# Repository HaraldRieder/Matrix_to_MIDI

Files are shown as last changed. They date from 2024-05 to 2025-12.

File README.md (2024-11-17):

## MIDI Controller mit Keyboard Diodenmatrix

Dieses Archiv enthält Dokumentation und Arduino-Quellcode zum Bau eines MIDI Instruments mit 6+6 Tastatur, die über eine Diodenmatrix abgefagt wird.
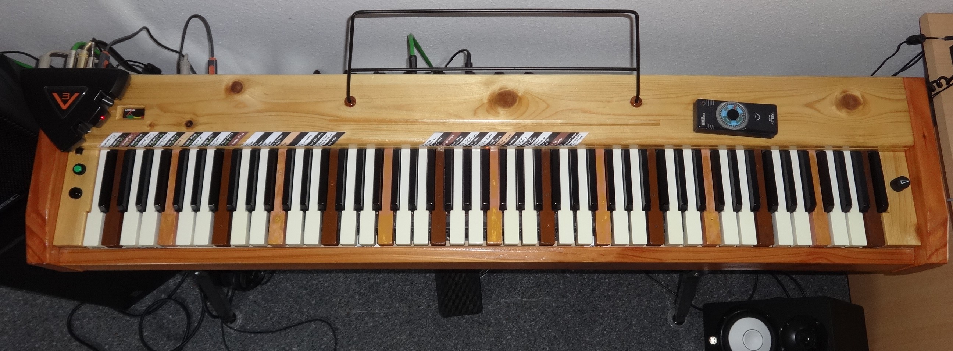
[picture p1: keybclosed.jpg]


Die Diodenmatrix basiert auf 8 Sammelleitungen und jeweils 11 Leitungen für Arbeits- und Ruhekontakte. Damit kann die Tastatur maximal 8x11=88 Tasten besitzen. Solche Matrizen wurden zum Beispiel in FATAR Tastaturen, die in Doepfer Masterkeyboards integriert wurden, eingesetzt.
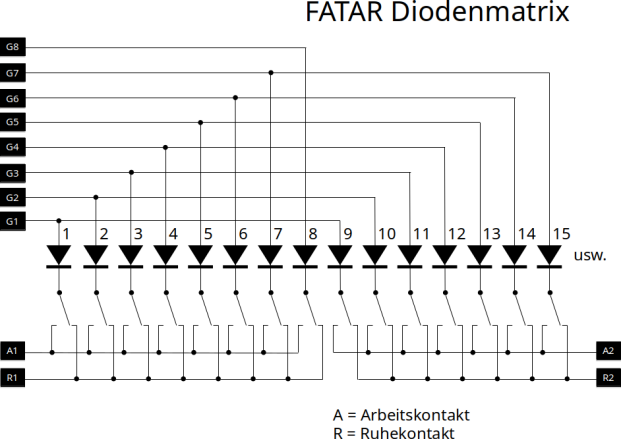
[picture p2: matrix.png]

Die Unterstützung anderer Tastaturen ist möglich, erfordert aber eine Code-Anpassung.

Ursprünglich als reines MIDI Keyboard mit hochwertiger Tastatur geplant hat sich das Projekt weiter entwickelt. Ein MIDI Modul, hier ein V3 Sound Grand Piano XXL, kann spezifisch angesteuert werden. Ein Keyboard-Splitpunkt wird unterstützt. Gesendet wird auf bis zu 3 MIDI Kanälen. Unterstützung anderer MIDI Module ist möglich, erfordert aber eine Code-Anpassung.

## Blockschaltbild und Anschlüsse
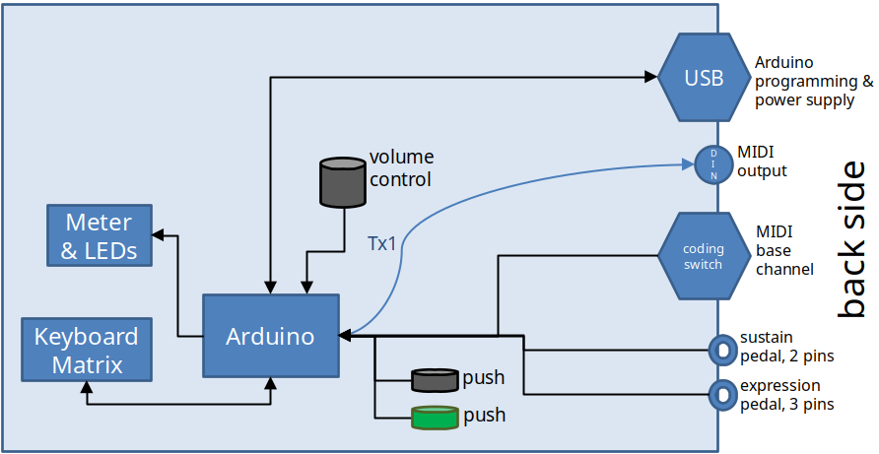
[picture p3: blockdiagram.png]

### Ein- und Ausgänge

- 5-pol. DIN Buchse MIDI Ausgang
- 6,3 mm Mono-Klinkenbuchse für Haltepedal
- 6,3 mm Stereo-Klinkenbuchse für Schwellerpedal
- USB Typ B Buchse für Arduino-Programmierung oder Stromversorgung. Praktisch: wird tatsächlich ein V3 Sound Modul verwendet, dann kann dessen USB Anschluss, der vom Herstellen eigentlich für einen Bluethooth-Stick vorgesehen ist, das MIDI Keyboard mit Strom mitversorgen.

### Bedienelemente

- Stufenschalter zur Festlegung der MIDI-Kanäle
- Drehregler rechts für Gesamtlautstärke
- Ein schwarzer und ein grüner Taster links
- Ein Zeigerinstrument mit schaltbarer Hintergrundbeleuchtung (weiße LED)
- Eine orange LED über der Tastaturmitte
- Die Tastatur selbst

## Schaltpläne

Zentraler Bestandteil der Elektronik ist ein Arduino Mega 2560 Board. Nur wenige Bauteile sind notwendig zur Anpassung an die Peripherie. Je Arbeits- und Ruhekontaktleitung der Tastaturmatrix wird ein 1 kOhm Widerstand benötigt.

Der Maximalausschlag des Zeigerinstruments kann mit Hilfe eines Trimmers justiert werden.

Die Pegel der externen Pedale werden über Kondensatoren leicht geglättet. Der 1,2 kOhm Widerstand schützt vor Kurzschlüssen, denn an der Buchse für das Schwellerpedal finden sich sowohl +5V als auch Masse. Das Schwellerpedal muss hochohmig sein, damit der 1,2 kOhm Widerstand nicht die Vollaussteuerung verhindert.
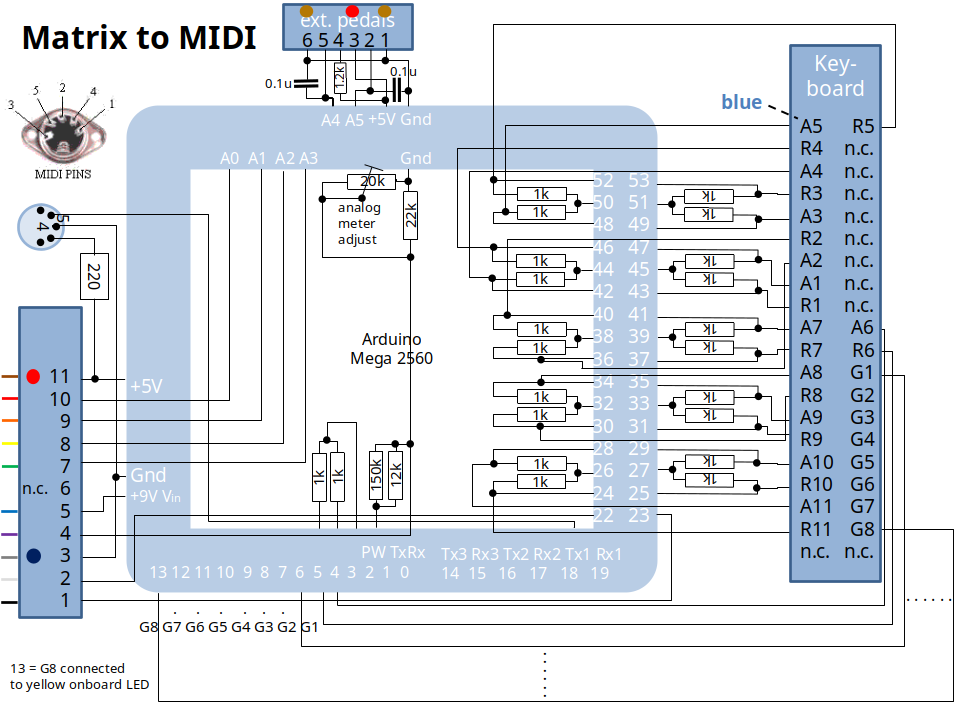
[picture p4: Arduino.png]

Besonderheit: Zur Einsparung von Arduino-Eingängen wird die Stellung des Codierschalters mittels 5 Widerständen D/A-gewandelt. Die Software reduziert den am Analogeingang gemessenen, 1024 Werte feinen digitalen Wert wieder in eine Schalterstellung von 0 bis 9.
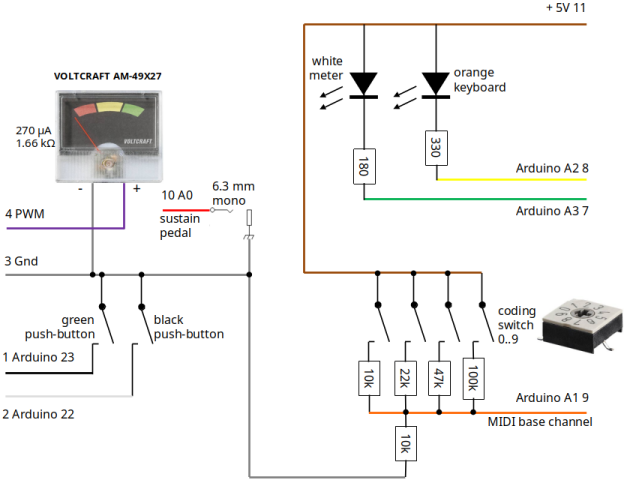
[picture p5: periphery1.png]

Die weiße LED ist die Hintergrundbeleuchtung des Zeigerinstruments, die orangene die über der Tastatur.
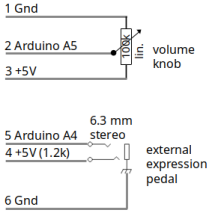
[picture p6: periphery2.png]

Das von mir verwendete Schwellerpedal von Dr. Böhm enthält ein logarithmisches 180° Potentiometer mit 470 kOhm. Die Software muss zurückrechnen. Im [Code](Matrix_to_MIDI.ino) vorgesehen ist aber auch der Anschluss linearer Potentiometer (siehe die Bedingung um den Aufruf von `delog()`).

## Hardware

Alles zusammen ist in einem selbstgebauten Holzgehäuse untergebracht. Die Tastatur kann zu Wartungszwecken ohne Werkzeug ausgebaut werden. Die obere Klappe wird lediglich durch 2 quadratische Permanentmagnete links und rechts geschlossen gehalten. Sie kann von Hand durch einen gewissen Krafteinsatz geöffnet werden.
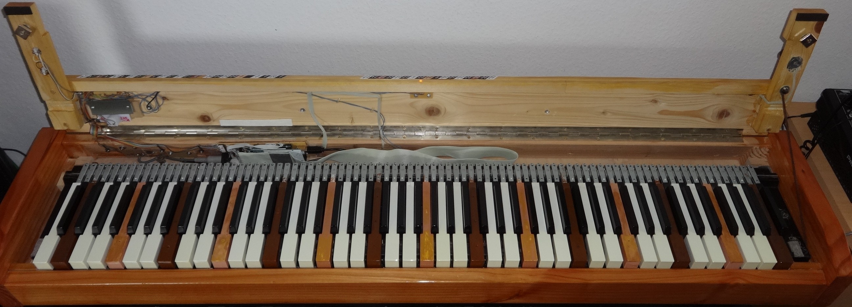
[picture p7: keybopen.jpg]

Die Tastatur wird durch 2 Klemmblöcke links und rechts fixiert. Bei geöffneter Klappe lassen sich diese Holzblöcke nach oben entnehmen. Danach kann die Tastatur nach hinten bis zum Anschlag geschoben und nach oben herausgenommen werden.

Arduino- mit Mother-Board (Lochrasterplatine) befinden sich stehend in der linken Hälfte. Um die zusammengesteckten Boards zu entnehmen müssen alle Steckverbinder zum Mother-Board gelöst werden. Die Boards werden nur durch die geschlossene Klappe fixiert und können bei geöffneter Klappe vorsichtig nach oben entnommen werden. Ein Ausbau der Tastatur ist nicht notwendig.

Dies ist das mit Abstand wartungsfreundlichste Keyboard, das ich in meinem Musikerleben hatte, und es gab derer nicht wenige.

## Bedienung

### MIDI-Kanäle einstellen

Das Instrument sendet auf bis zu 3 aufeinanderfolgenden MIDI Kanälen, die über den Codierschalter einzustellen sind. Der Codierschalter wird nur beim Hochfahren ausgelesen
in der Zeit, in der die Hintergrundbeleuchtung des Zeigerinstruments an ist. Für den Wechsel der MIDI Kanäle muss das Instrument also aus- und wieder eingeschaltet werden.

Circa 5 Sekunden nach dem Einschalten werden außerdem

* ein General MIDI Reset gesendet (SYSEX)
* V3 Reverb Type auf Room 2 und Effect Type auf Chorus 1 gestellt (SYSEX)
* V3 Main und AUX Equalizer flach[^1] gestellt (MIDI NRPNs)

[^1]: Nach dem Einschalten sind die XXL EQs *nicht* flach eingestellt!

#### Ohne Split

Nach dem Einschalten ist die Tastatur nicht geteilt. Das Instrument sendet auf dem Kanal, der am Codierschalter eingestellt wurde. Dabei fängt MIDI bei 1 an zu zählen und der Codierschalter bei 0. Das Haltepedal bestimmt den _Sustain_ Wert, der Schweller den _Expression_ Wert. Oft bestimmt der _Expression_ Controller die Lautstärke, das hängt vom MIDI Modul und dessen Einstellungen ab.

*Beispiel: Der Codierschalter steht auf 4, dann wird auf MIDI-Kanal 5 gesendet.*

#### Mit Split

Das Instrument sendet auf 3 aufeinanderfolgenden Kanälen. Der linke Tastaturbereich sendet auf dem 1. der Kanäle, der rechte Tastaturbereich sendet auf dem 2. und 3. der Kanäle. Der Schweller regelt den _Expression_ Wert auf dem 2. der Kanäle.

*Beispiel: Der Codierschalter steht auf 2, dann sendet der linke Tastaturbereich auf MIDI-Kanal 3, der rechte Tastaturbereich sendet parallel auf den Kanälen 4 und 5. Der Schweller regelt nur Kanal 4.*

Im Splitmodus hat man normalerweise links und rechts verschiedene Sounds. Mit dem Schweller lässt sich auf der rechten Seite ein weiterer, dritter Sound als _Layer_ hinzuregeln. Natürlich kann man auf dem 3. der Kanäle auch einen stummen Sound einstellen und trotzdem mit dem Schweller den 2. der Kanäle regeln.

##### Transponierung

Der rechte Tastaturbereich transponiert fest um -12.

Der linke Tastaturbereich transponiert zunächst nicht. Diese Einstellung eignet sich dazu, mit der linken Hand Bass zu spielen. Da beim monophonen Bassspiel _Sustain_ so gut wie nie benötigt wird, sendet das Haltepedal auf dem 2. und den 3. der Kanäle, also für den rechten Bereich.

Der linke Bereich kann auf eine Transponierung +12 umgeschaltet werden. Diese Einstellung eignet sich dazu, mit der linken Hand Akkorde zu spielen. Das Haltepedal sendet dann auf dem 1. der Kanäle, also für den linken Bereich.

### Globale Anschlagsdynamik einstellen

Durch langes Drücken (> 2,5 Sekunden) des schwarzen Tasters gelangt man in den Justiermodus für die globale Anschlagsempfindlichkeit. Das Zeigerinstrument wird beleuchtet und zeigt den eingestellten Wert an. Drückt man eine Taste, wird die MIDI _Velocity_ angezeigt, wie sie über MIDI gesendet wird. Dem Vollausschlag des Zeigers entspricht ein Wert von 127. Nach Loslassen der Taste wird wieder die eingestellte globale Empfindlichkeit angezeigt. Der Empfindlichkeitswert kann mit dem grünen Taster schrittweise vermindert und mit dem schwarzen Taster erhöht werden.

Diese Funktion ist zur Anpassung an das verwendete MIDI Modul gedacht.

Um den Justiermodus zu verlassen muss der schwarze Taster nochmals lange gedrückt werden.

### Anschlagsdynamik je Taste justieren

Durch langes Drücken (> 2,5 Sekunden) des grünen Tasters gelangt man in den Feinjustiermodus. Die Empfindlichkeit lässt sich je Taste nachjustieren. Oft sind Ober- und Untertasten aufgrund der Bauweise der jeweiligen Tastatur verschieden zu justieren. Drückt man eine Taste, wird die MIDI _Velocity_ angezeigt, wie sie über MIDI gesendet wird. Dem Vollausschlag des Zeigers entspricht ein Wert von 127. Nach Loslassen der Taste wird die eingestellte Empfindlichkeit der Taste angezeigt. Der Empfindlichkeitswert kann mit dem grünen Taster schrittweise vermindert und mit dem schwarzen Taster erhöht werden.

Diese Funktion ist zur Anpassung an die verwendete Tastatur gedacht.

Um den Feinjustiermodus zu verlassen muss der grüne Taster nochmals lange gedrückt werden.

### Keyboard Split

Durch gleichzeitiges (kurzes) Drücken beider Taster lässt sich ein Splitpunkt festlegen. Die orangene LED blinkt, bis eine Taste gedrückt wird. Die gedrückte Taste legt den Splitpunkt fest. Im Splitmodus leuchtet die orangene LED heller.

Um den Splitmodus zu verlassen müssen wieder beide Taster gleichzeitig gedrückt werden. Die orangene LED leuchtet nun dunkler, so wie nach dem Einschalten.

#### Transponierung linker Bereich

Im Splitmodus lässt sich die Transponierung des linken Bereichs zwischen 0 und +12 umschalten. Dazu ist der schwarze Taster kurz zu drücken. Das Zeigerinstrument wird für 1,5 Sekunden beleuchtet und meldet die eingestellte Transponieren zurück, das heißt der Zeiger befindet sich entsprechend am linken oder am rechten Anschlag.

### V3 Grand Piano Ansteuerung
Unterstützt wird das Einstellen von

- Sounds mittels Bank Select und Program Change Nachrichten.
- Registrierungen im Sinne von V3 Sound Registrierungen für die bis zu 3 Kanäle im Splitmodus.

#### Sounds

Ohne Splitpunkt kann keine Registrierung eingestellt werden. Es können auch keine Sounds aus der Bass-Gruppe (grün) eingestellt werden.

Nach kurzem Drücken des grünen Tasters lässt sich ein Sound auswählen. Die orangene LED blinkt, bis eine Taste aus dem linken Bereich gedrückt wird. Die gedrückte Taste wählt den Sound aus. Die Sounds sind im [Quellcode](V3GrandPianoXXL.h) festzulegen. Aufkleber helfen beim Finden der zu drückenden Taste.

Die Namen der Sounds wurden denen aus dem V3 Handbuch entlehnt, z.B. _GP Hamburg_ für _Grand Piano Hamburg_ oder _Upright Bs_ für _Upright Jazz Bass_.

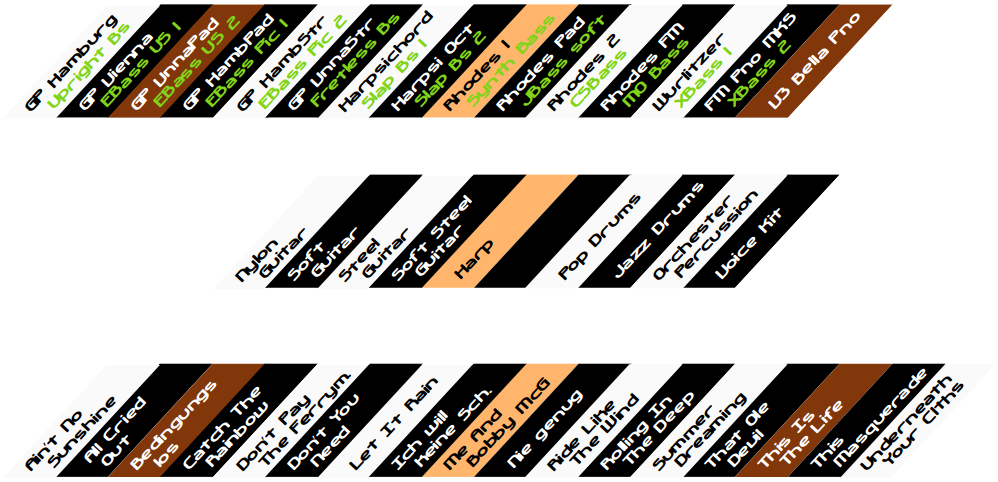
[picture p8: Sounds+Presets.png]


#### Registrierungen

Eine Registrierung besteht aus globalen Einstellungen und 3 Presets.

Als globale Einstellungen werden unterstützt

- Reverb Type
- Effect Type

Ein Preset besteht derzeit aus den kanalspezifischen Einstellungen

- Bank Select + Program Change
- Channel Volume
- Coarse Tuning
- Reverb Level
- Choruse Level
- Attack
- Decay
- Release
- Cutoff Frequency

Nach kurzem Drücken des grünen Tasters lässt sich eine Registrierung auswählen. Die orangene LED blinkt, bis eine Taste gedrückt wird. Eine gedrückte Taste ab der Tastaturmitte wählt die Registrierung aus. Die Registrierungen sind im [Quellcode](V3GrandPianoXXL.h) festzulegen. Aufkleber helfen beim Finden der zu drückenden Taste. Die Registrierungen wurden nach den Musiktiteln benannt, wo sie erstmalig zum Einsatz kamen, z.B. _Ain't No Sunshine_.

Wird bei blinkender LED eine Taste gewählt, die einen Sound auswählt (linke Tasten) und nicht eine Registrierung, dann betrifft dies den 1. der Kanäle, also den linken Bereich. So lässt sich zum Beispiel im Splitmodus nach Auswahl der Registrierung nachträglich der Bass- (kein Transpose) oder Begleit-Sound (bei Transpose +12) ändern.

### Zustandsdiagramme
#### Einschalten, Justieren, Split festlegen
Nach dem Einschalten wird nach einigen Sekunden der _Normalzustand_ `playing` erreicht. Alle anderen Zustände wird man nur von Zeit zu Zeit besuchen.
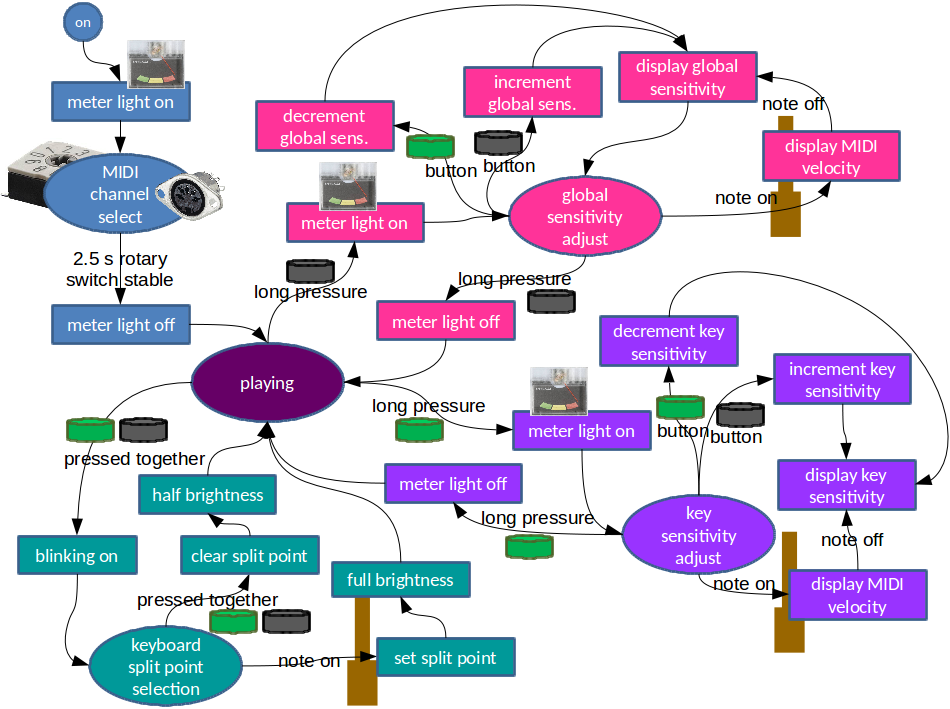
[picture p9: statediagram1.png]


#### Transponieren und Sound/Preset auswählen
`playing` ist identisch mit dem bereits erwähnten Normalzustand. Um das obige Diagramm nicht zu überfrachten, wurde dieses weitere Diagramm erstellt.
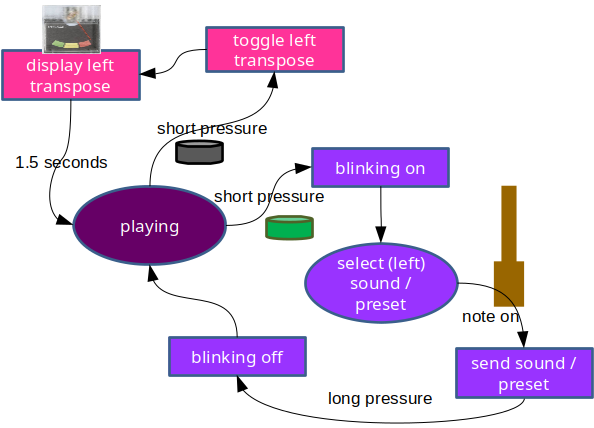
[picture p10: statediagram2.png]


## FATAR Tastatur, sehr hochwertig aber inklusive Zeitbombe

Meine LMK3 Tastatur wurde wahrscheinlich im Jahr 1991 hergestellt und dank leicht zu reinigender, versilberter Spiralschalter funktioniert sie 2024 noch tadellos.
Allerdings hat die Tastatur einen Design-Fehler, der mit ziemlichem Aufwand behoben werden muss.
Für Dämpfung sorgen Filze und Gummis. Die Gummis haben eine zusätzliche Funktion: sie führen die Tasten seitlich. Und das ist ein Problem.
Gummiabrieb sammelt sich schon nach Monaten auf den metallenen Innenseiten der Tasten, und danach reibt Gummi auf Gummi.
Wird die Taste genau senkrecht nach unten gedrückt, stört es nicht. Mit seitlicher Kraft nach rechts oder links widerborstet sie aber erheblich.
So kann nicht ernsthaft Klavier gespielt werden!

Dagegen habe ich jahrelang mit nähgarnumwickelten Gummis gearbeitet. Bei 88 Gummis ist das ein Riesenaufwand.
Und nach Jahren sind manche Garne abgerieben und es bremst wieder bei seitlichem Niederdrücken.

Bei neu aufgetauchten Widerborsten mussten nun die seitlichen Gummiführungen ganz weichen. Ich habe sie weggeschnitten, wodurch von jedem Gummi nur noch Ober- und Unterteil übrig bleiben.
Diese werden nicht mehr von vorne auf die vorgesehenen Stahlhalterungen geschoben, was mangels Loch nicht mehr geht, sondern aufgeklebt.
Die seitliche Führungsarbeit wird von 0,9 mm Garnierungsfilzen (von Meyne) übernommen. Bisher funktioniert das einwandfrei.
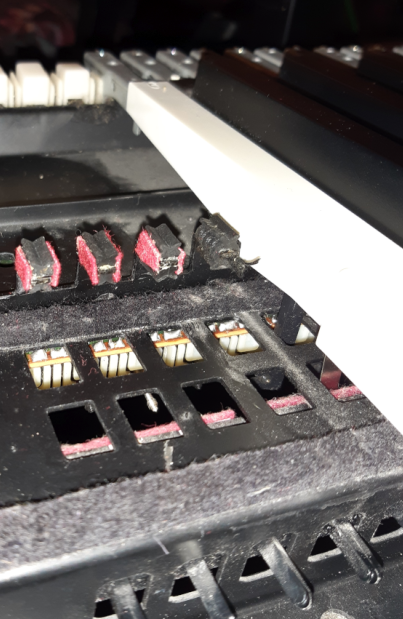
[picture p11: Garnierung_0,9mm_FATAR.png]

Auf dem Bild sieht man links 3 zerschnittene Gummis mit seitlichen, roten Filzführungen, daneben noch ein garnumwickelter Gummi.

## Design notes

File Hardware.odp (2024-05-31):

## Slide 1

push

push

back side

volume
control

USB

Arduino

programming &
power supply

DIN

MIDI

output

MIDI

base

channel

Meter

& LEDs

Tx1

coding switch

Arduino

Keyboard
Matrix

sustain

pedal, 2 pins

expression

pedal, 3 pins

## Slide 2

Arduino

Mega 2560

52 53

50 51

48 49

46 47

44 45

42 43

40 41

38 39

36 37

34 35

32 33

30 31

28 29

26 27

24 25

22 23

Tx3 Rx3 Tx2 Rx2 Tx1 Rx1
14 15 16 17 18 19

+5V

Gnd +9V Vin

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
Matrix to MIDI

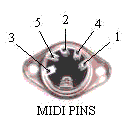
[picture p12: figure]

12k

150k

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
Key-

board

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
n.c.

ext. pedals

6 5 4 3 2 1

1.2k

A4 A5

A0 A1 A2 A3

0.1u

0.1u

+5V Gnd

Gnd

blue

R5

n.c.

n.c.

n.c.

n.c.

n.c.

n.c.

n.c.

n.c.

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
n.c.

PW TxRx

13 12 11 10 9 8 7 6 5 4 3 2 1 0

analog
meter

adjust

n.c.

G8 G7 G6 G5 G4 G3 G2 G1

13 = G8 connected

to yellow onboard LED

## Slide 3

330

180

10k

22k

47k

100k

10k

+ 5V 11

VOLTCRAFT AM-49X27

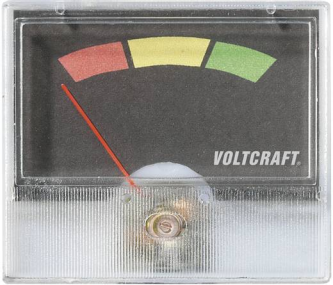
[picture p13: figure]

- +

white

meter

orange

keyboard

270 μA

1.66 kΩ

Arduino A2 8

Arduino A3 7

4 PWM

10 A0

sustain
pedal

6.3 mm
mono

n.c.

3 Gnd

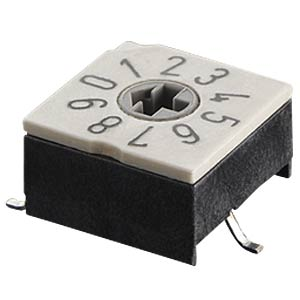
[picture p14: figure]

Arduino A1 9

green

push-button

1 Arduino 23

2 Arduino 22

black

push-button

coding

switch

0..9

MIDI base channel

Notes: 7

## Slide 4

100k
lin.

1 Gnd

2 Arduino A5

3 +5V

volume
knob

5 Arduino A4

4 +5V (1.2k)

6.3 mm
stereo

external
expression
pedal

6 Gnd

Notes: 7

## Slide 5

2.5 s rotary

switch stable

long pressure

button

button

note on

note off

long pressure

long pressure

long pressure

button

button

note on

note off

pressed together

note on

pressed together

on

meter light on

MIDI channel select

decrement global sens.

increment global sens.

display global sensitivity

display MIDI velocity

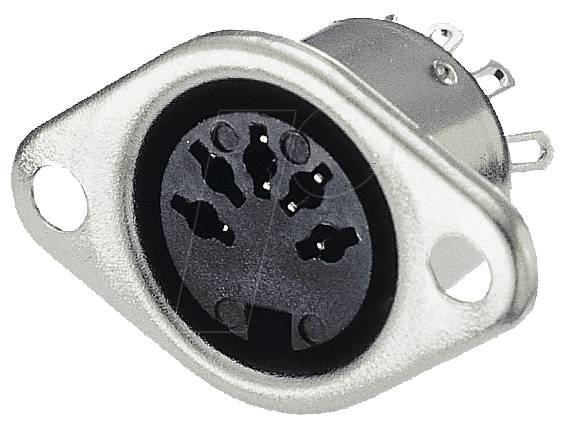
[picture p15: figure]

meter light on

global sensitivity

adjust

meter light off

meter light off

playing

decrement key sensitivity

increment key sensitivity

meter light on

half brightness

meter light off

display key sensitivity

key sensitivity

adjust

blinking on

clear split point

full brightness

display MIDI velocity

keyboard split point selection

set split point

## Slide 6

short pressure

1.5 seconds

short pressure

long pressure

note on

display left
transpose

toggle left transpose

blinking on

playing

select (left) sound / preset

blinking off

send sound / preset

## FATAR Diodenmatrix

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
usw.

A1

A2

R1

A = Arbeitskontakt

R = Ruhekontakt

R2

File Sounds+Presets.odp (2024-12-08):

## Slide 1

GP Vienna
EBass US 1

GP Hamburg
Upright Bs

GP VnnaPad
EBass US 2

Rhodes 1
Synth Bass

GP HambPad
EBass Pic 1

GP HambStr
EBass Pic 2

Harpsichord
Slap Bs 1

GP VnnaStr
Fretless Bs

Harpsi Oct
Slap Bs 2

Rhodes Pad
JBass soft

Rhodes FM
MO Bass

FM Pno MKS
XBass 2

Rhodes 2
CSBass

Wurlitzer
XBass 1

V3 Bella Pno

Harp

Nylon

Guitar

Steel

Guitar

Soft

Guitar

Soft Steel
Guitar

Jazz Drums

Voice Kit

Pop Drums

Orchester

Percussion

All Cried

Out

Ain’t No

Sunshine

Bedingungs

los

Me And

Bobby McG

Catch The

Rainbow

Don’t Pay

The Ferrym.

Let It Rain

Don’t You

Need

Ich will

keine Sch.

Nie genug

Rolling In

The Deep

That Ole

Devil

Ride Like

The Wind

Summer

Dreaming

This Is

The Life

Underneath

Your Clths

This

Masquerade

Ain’t Nobody

Streifenhöhe 3 cm, Streifenbreite/Tastenabstand 1,375 cm, Impress Grid dx = 1,38 cm dy = 1 cm, Schriftwinkel atan(3/2/1,38) = 47,39°

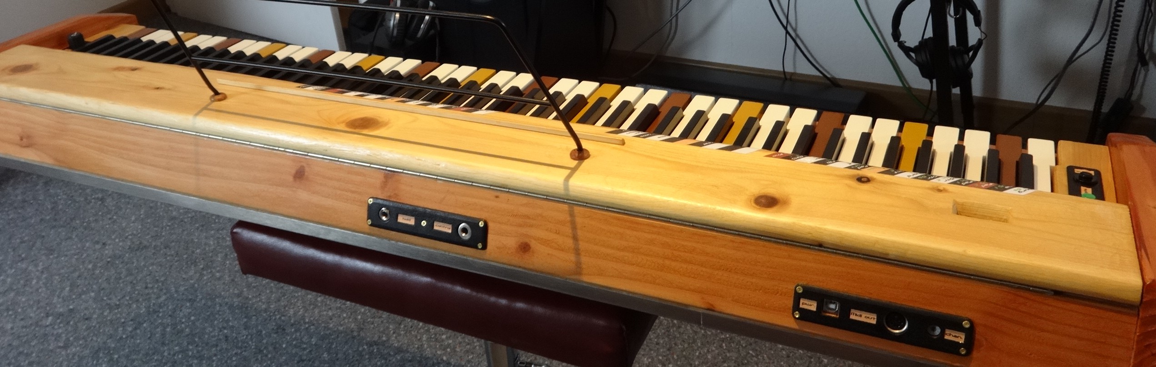
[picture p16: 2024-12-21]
refurbished_back.JPG

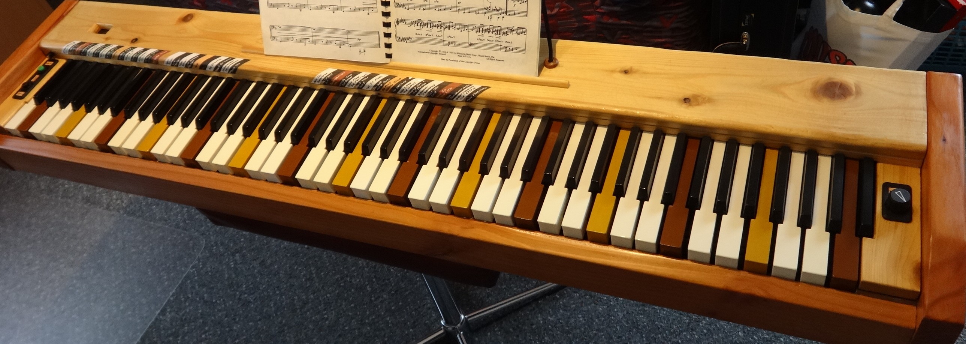
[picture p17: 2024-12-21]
refurbished_front.JPG

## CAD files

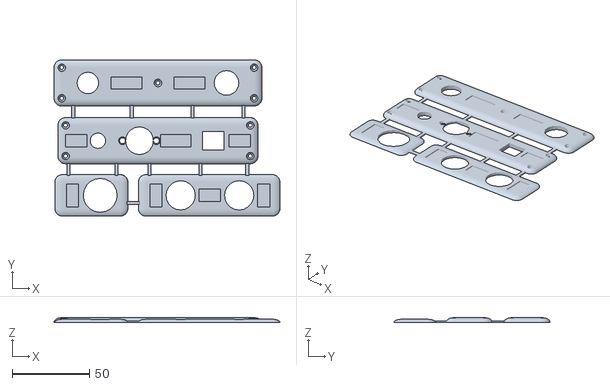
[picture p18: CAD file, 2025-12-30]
Matrix to MIDI Plates.stl
146.8 x 101.5 x 3.00

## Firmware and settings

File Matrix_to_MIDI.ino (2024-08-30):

/**************** WARNING ****************

This project runs successfully on Arduino Mega 2560 when built with Arduino 2: 1.0.5+dfsg2-4 IDE.
Chosen board: Arduino Mega 2560 or Mega ADK

This project did out-of-the-box *NOT* run on Arduino Mega 2560 when built with Arduino 1.8.10!
The software crashed and the board booted cyclically.

I found out that the direct port I/O in Matrix.h was responsible. For other reasons
I changed the compiler option to -O3 and this seems to have repaired the 
direct port I/O code, too. See platform.txt.

***************** WARNING *****************/

#include <midi_Message.h>
#include <midi_Namespace.h>
#include <MIDI.h>
#include <midi_Defs.h>
#include <midi_Settings.h>

#include <EEPROM.h>
#include "Matrix.h"
#include "Dynamic.h"
#include "Matrix_to_MIDI.h"
#include "ScaleTune.h"
#include "CodingSwitch.h"
#include "V3GrandPianoXXL.h"

MIDI_CREATE_INSTANCE(HardwareSerial, Serial1, midi1);

midi::Channel channel = 1;

/*--------------------------------- setup and main loop ---------------------------------*/

int slice_counter = 0;
const int n_slices = 6;

const int keyboard_led_pin = A2; // = F2 ATMega port+bit

const int no_key = -1;
int last_key = no_key;
int split_position = no_key;
int left_transpose = 0;

const int black_button_pin = 22;
const int green_button_pin = 23;
const int external_switch_pin = A0; // = F0 ATMega port+bit
const int external_control_pin = A4; 
int external_control_val = 1023; // 0..1023 analog value
int external_val = MIDI_CONTROLLER_MAX; // 0..127 MIDI value
const int volume_control_pin = A5;
int volume_control_val = 1023; // 0..1023 analog value
int volume_val = MIDI_CONTROLLER_MAX; // 0..127 MIDI value
boolean black_button = false; // "up"
boolean green_button = false; // "down"
int external_switch = LOW;

void setup() {
  Serial.begin(9600); // debugging
  pinMode(black_button_pin, INPUT_PULLUP);
  pinMode(green_button_pin, INPUT_PULLUP);
  pinMode(external_switch_pin, INPUT_PULLUP);
  pinMode(meter_pin, OUTPUT);
  pinMode(meter_led_pin, OUTPUT);
  pinMode(keyboard_led_pin, OUTPUT);
  digitalWrite(keyboard_led_pin, HIGH);
  
  // user has 5 seconds (re-triggerable timer) to adjust MIDI channel
  digitalWrite(meter_led_pin, LOW);
  channel = readCodingSwitchValue(A1) + 1; // 0=omni, 1..16 are individual channels, 17=off
  displayChannel(channel);
  for (int i = 1; i <= 20; i++) {
    delay(250);
    byte newChannel = readCodingSwitchValue(A1) + 1;
    displayChannel(newChannel);
    if (newChannel != channel) {
      channel = newChannel;
      i = 0;
    }
  } 
  digitalWrite(meter_led_pin, HIGH);
  display(0);
  // V3 XXL needs these 5 seconds to get ready!
  
  setupMatrixPins();

  readSettings();
  initVelocities(global_sens_to_exponent(settings.sensitivity));

  midi1.begin(1/*dummy input channel*/);
  sendGMReset(midi1);
  sendReverbType(1, midi1); // Room 2
  for (int i = 0; i < 3; i++) {
    midi1.sendControlChange(midi::Effects1, 15, channel+i); // Room 2 -> lower reverb send level

  }
  sendEffectType(0, midi1); // Chorus 1
  flattenEQs(midi1);

  // disable timers / avoid jitter
  //TIMSK0 = 0; leave timer 0 enabled so that we still have delay() and millis() but not tone()
  TIMSK1 = 0;
  TIMSK2 = 0;
  //TIMSK3 = 0; we need timer 3 for PWM at pin 2
  TIMSK4 = 0;
  TIMSK5 = 0;

  Serial.println("ready");
}

// max. time Arduino consumes between 2 calls of loop()
int max_ex_scan_time_us = 0;
int t_start = -1;

// blinking LEDs
const int period = 400/*ms*/;
unsigned long last_blink = 0/*ms*/;
boolean keyboard_led_on = false;

/* 3 dodecimes to select left sounds */
const midi::DataByte right_sounds_start = 12*3;

// report the max. time between calls of scanMatrix, highest observed value: 24 us
//#define DEBUG_EX_SCAN_TIME

State state = idle;

void loop() {
  static int i_led;

  unsigned long t = millis();
  int inval;
  switch (slice_counter) {
    case 0:
      buttons(t);
      break;
    case 2:
      inval = analogRead(volume_control_pin);
      // if changed, with +-2 jitter suppression
      if (inval > volume_control_val + 2 || inval < volume_control_val - 2) {
        volume_control_val = inval;
        inval /= 8;
        if (inval != volume_val) {
          sendMasterVolume(volume_val = inval, midi1);
          //Serial.print("volume val "); Serial.println(volume_val);
        }
      }
      break;
    case 4:
      inval = analogRead(external_control_pin);
      // if changed, with +-2 jitter suppression
      if (inval > external_control_val + 2 || inval < external_control_val - 2) {
        external_control_val = inval;
        if (true) inval = delog(inval)/8; // for logarithmic/audio pedals
        else inval /= 8; // for linear pedals
        if (inval != external_val) {
          externalControl(external_val = inval);
          //Serial.print("external val "); Serial.println(external_val);
        }
      }
      break;
    default:       
      externalSwitch();
  }
  
  switch (state) {
    case idle: case global_sensitivity:
      switch (++i_led) {
        case 10:
          //digitalWrite(keyboard_led_pin, LOW);
          PORTF &= 0xfb;
          keyboard_led_on = true;
          break;
        case 11:
          if (split_position == no_key) {
            //digitalWrite(keyboard_led_pin, HIGH);
            PORTF |= 0x04;
            keyboard_led_on = false;
          }
          i_led = 0;
          break;
      }
      break;
    default:
      if (t >= last_blink + period) {
        last_blink = t;
        process(toggle_led, -1, -1);
      }
  }
  
  #ifdef DEBUG_EX_SCAN_TIME
  if (t_start > 0) {
    int ex_scan_time_us = micros() - t_start;
    if (ex_scan_time_us > max_ex_scan_time_us) {
      max_ex_scan_time_us = ex_scan_time_us;
      Serial.print(max_ex_scan_time_us); Serial.println(" microseconds max. ex. scan");
    }
  }
  // typical max. value: 20 microseconds
  #endif
  
  scanMatrix();

  #ifdef DEBUG_EX_SCAN_TIME
  t_start = micros();
  #endif
  
  slice_counter++;
  if (slice_counter >= n_slices) {
    slice_counter = 0;
  }
}

int delog(int value) {
  static int half = 120;
  if (value <= half) {
    //Serial.print("delog - ");Serial.print(value);Serial.print("->");Serial.println((long)value * 512 / half);
    return (long)value * 512 / half;
  }
  //Serial.print("delog + ");Serial.print(value);Serial.print("->");Serial.println((long)(value - half) * 511 / (1023 - half) + 512);
  return (long)(value - half) * 511 / (1023 - half) + 512;
}

/*--------------------------------- state event machine ---------------------------------*/

//#define DEBUG_STATE_MACHINE
/**
 * The state event machine for the user interface.
 * @param event user action
 * @value optional value, meaning depends on event type
 */
void process(Event event, int value, int value2) {
  
  #ifdef DEBUG_STATE_MACHINE
  switch (state) {
    case idle:               Serial.print("idle");           break;
    case wait_for_split:     Serial.print("wait for split"); break;
    case wait_for_preset:    Serial.print("wait for preset");break;
    case global_sensitivity: Serial.print("global sens.");   break;
    case key_sensitivity:    Serial.print("key sens.");      break;
  }
  Serial.print(" <- "); 
  switch (event) {
    case up_long:    Serial.println("up long");    break;
    case down_long:  Serial.println("down long");  break;
    case up_short:   Serial.println("up short");   break;
    case down_short: Serial.println("down short"); break;
    case both:       Serial.println("both");       break;
    case note_on:    Serial.println("note on");    break;
    case note_off:   Serial.println("note off");   break;
    case toggle_led: Serial.println("toggle led"); break;
  }
  delay(150);
  #endif
  
  if (event == toggle_led) {
    //digitalWrite(keyboard_led_pin, (keyboard_led_on = !keyboard_led_on) ? LOW : HIGH);
    if (keyboard_led_on = !keyboard_led_on) {
      PORTF &= 0xfb;
    } else {
      PORTF |= 0x04;
    }
    return;
  }

  switch (state) {

    case idle:
      switch (event) {
        case up_long:
          digitalWrite(meter_led_pin, LOW);
          state = global_sensitivity;
          last_key = no_key;
          display(settings.sensitivity);
          return;
        case down_long:
          digitalWrite(meter_led_pin, LOW);
          state = key_sensitivity;
          last_key = no_key;
          display(meter_max);
          return;
        case up_short: 
          if (split_position != no_key) {
            // toggle left transpose
            digitalWrite(meter_led_pin, LOW);
            if (left_transpose == 0) {
              left_transpose = 12;
              display(meter_max);
            }
            else {
              left_transpose = 0;
              display(0);
            }
            delay(1500);
            digitalWrite(meter_led_pin, HIGH);
            display(0);
          }
          return;
        case down_short:
          state = wait_for_preset;
          return;
        case both:
          if (split_position == no_key) {
            state = wait_for_split;
          }
          else {
            split_position = no_key;
          }
          return;
      }
      return;
      
    case wait_for_split:
      switch (event) {
        case note_off: 
          split_position = value;
          state = idle;
          //digitalWrite(keyboard_led_pin, HIGH); 
          PORTF |= 0x04;
          keyboard_led_on = true;
          return;
        case both:
          state = idle;
          split_position = no_key;
          return;
      }
      return;

    case wait_for_preset:
      switch (event) {
        case note_off:
          if (split_position == no_key) {
            if (value < n_sounds) {
              sendSound(sounds[value], channel, midi1);
              sendFineTune(0x40, channel, midi1);
              sendFineTune(0x40, channel + 1, midi1);
              sendFineTune(0x40, channel + 2, midi1);
              sendCoarseTune(0x40, channel, midi1);
              sendCoarseTune(0x40, channel + 1, midi1);
              sendCoarseTune(0x40, channel + 2, midi1);
              externalControl(external_val);
              state = idle;
            }
          }
          else {
            if (value < right_sounds_start) {
              // set left sound
              if (left_transpose == 0) {
                if (value < n_bass_sounds) {
                  sendSound(bass_sounds[value], channel, midi1);
                  state = idle;
                }
              } 
              else {
                if (value < n_sounds) {
                  sendSound(sounds[value], channel, midi1);
                  state = idle;
                }
              }
              sendFineTune(0x38, channel, midi1);
              sendCoarseTune(0x40, channel, midi1);
            }
            else {
              value -= right_sounds_start;
              if (value < n_registrations) {
                sendRegistration(registrations[value], channel, midi1);
                externalControl(external_val);
                state = idle;
              }
            }
          }
          return;
        case up_short:
        case down_short:
          state = idle;
          return;
      }
      return;
      
    case global_sensitivity:
      switch (event) {
        case note_on:
          // display calculated MIDI velocity value
          display(value2 << 1);
          break;
        case note_off:
          // display global sensitivity 
          display(settings.sensitivity);
          break;
        case up_short:
          if (settings.sensitivity < meter_max) {
            initVelocities(global_sens_to_exponent(settings.sensitivity += global_delta));
            Serial.print("sens. "); Serial.println(settings.sensitivity);
          }
          display(settings.sensitivity);
          return;
        case down_short:
          if (settings.sensitivity > 0) {
            initVelocities(global_sens_to_exponent(settings.sensitivity -= global_delta));
            Serial.print("sens. "); Serial.println(settings.sensitivity);
          }
          display(settings.sensitivity);
          return;
        case up_long:
        case down_long:
          // exit
          state = idle;
          saveSettings();
          display(0);
          digitalWrite(meter_led_pin, HIGH);
          return;
      }
      return;
      
    case key_sensitivity:
      switch (event) {
        case note_on:
          last_key = value;
          // display calculated MIDI velocity value
          display(value2 << 1);
          break;
        case note_off:
          // display sensitivity of last key
          display(magnify(settings.sensitivities[last_key]));
          break;
        case up_short:
          if (last_key != no_key) {
            if (settings.sensitivities[last_key] < meter_max) {
              settings.sensitivities[last_key] += meter_delta;
              Serial.print("sens. "); Serial.println(settings.sensitivities[last_key]);
            }
            display(magnify(settings.sensitivities[last_key]));
          }
          return;
        case down_short:
          if (last_key != no_key) {
            if (settings.sensitivities[last_key] > 0) {
              settings.sensitivities[last_key] -= meter_delta;
              Serial.print("sens. "); Serial.println(settings.sensitivities[last_key]);
            }
            display(magnify(settings.sensitivities[last_key]));
          }
          return;
        case up_long:
        case down_long:
          // exit
          state = idle;
          saveSettings();
          display(0);
          digitalWrite(meter_led_pin, HIGH);
          return;
      }
      return;
  }  
}

/*--------------------------------- push-buttons ---------------------------------*/

const unsigned long long_time = 2500; 

void buttons(unsigned long t_millis) {
  static boolean discard_next_short = false;
  static unsigned long last_switch_time;
  
  //int val = digitalRead(rocker_switch_1_pin);
  int val = PINA & 0b01;
  if (val == 0) {
    if (!black_button) {
      black_button = true;
      last_switch_time = t_millis;
    }
    else {
      if (t_millis >= last_switch_time + long_time) {
        process(up_long, -1, -1);
        last_switch_time = t_millis;
        discard_next_short = true;
      }
    }
  }
  else if (black_button) {
    // black/up button released
    black_button = false;
    if (discard_next_short) {
      discard_next_short = false;
    }
    else if (t_millis <= last_switch_time + long_time) {
      if (green_button) {
        process(both, -1, -1);
        discard_next_short = true;
      } else {
        process(up_short, -1, -1);
      }
    }
  }
  //val = digitalRead(rocker_switch_2_pin);
  val = PINA & 0b10;
  if (val == 0) {
    if (!green_button) {
      green_button = true;
      last_switch_time = t_millis;
    }
    else {
      if (t_millis >= last_switch_time + long_time) {
        process(down_long, -1, -1);
        last_switch_time = t_millis;
        discard_next_short = true;
      }
    }
  }
  else if (green_button) {
    // green/down button released
    green_button = false;
    if (discard_next_short) {
      discard_next_short = false;
    }
    else if (t_millis <= last_switch_time + long_time) {
      if (black_button) {
        process(both, -1, -1);
        discard_next_short = true;
      } else {
        process(down_short, -1, -1);
      }
    }
  }
}

/*--------------------------------- ext. switch ---------------------------------*/
//#define DEBUG_SUSTAIN
/**
 * Reads external switch value and sends MIDI sustain control change if necessary.
 * @return true on value change
 */
void externalSwitch() {
  int val = digitalRead(external_switch_pin);
  //int val = (PINF & 0x01 == 0) ? LOW : HIGH;
  if (val == external_switch) {
    // no change
    return;
  }
  midi::DataByte ctrlval = (external_switch = val) == HIGH ? 127 : 0;
  if (split_position == no_key) {
    midi1.sendControlChange(midi::Sustain, ctrlval, channel);
  }
  else if (left_transpose != 0) {
    // sustain pedal controls left section
    midi1.sendControlChange(midi::Sustain, ctrlval, channel);
  } 
  else {
    // sustain pedal controls right section
    midi1.sendControlChange(midi::Sustain, ctrlval, channel + 1);
    midi1.sendControlChange(midi::Sustain, ctrlval, channel + 2);
  }
  #ifdef DEBUG_SUSTAIN
  if (external_switch) {
    Serial.println("sustain on");
  }
  else {
    Serial.println("sustain off");
  }    
  #endif
}

void externalControl(int value) {
  if (split_position == no_key) {
    midi1.sendControlChange(midi::ExpressionController, value, channel);
  }
  else {
    // expression pedal controlling 1st right sound
    midi1.sendControlChange(midi::ExpressionController, value, channel + 1);
  }
}

/*--------------------------------- event from matrix ---------------------------------*/

/* lowest key */
const midi::DataByte A = 21;
const midi::DataByte DefaultVelocity = 80;

// report calculated MIDI velocity
//#define DEBUG_VELOCITY

void handleKeyDownEvent(byte key, int t_raw) {
    midi::DataByte note = key + A;
    byte chan;
    boolean duplicate = false;
    if (split_position == no_key) {
      chan = channel;
    } 
    else if (key < split_position) {
      // left section or whole keyboard
      chan = channel;
      note += left_transpose;
    } 
    else {
      // right section
      chan = channel + 1;
      note -= split_position >= 12 ? 12 : 0;
      duplicate = true;
    }
    chan &= 0xf;
    int t = t_raw - settings.sensitivities[key] + meter_mean;
    if (t >= t_max)
      t = t_max - 1;
    else if (t < 0)
      t = 0;
    if (state != wait_for_split && state != wait_for_preset) {
      midi1.sendNoteOn(note, velocities[t], chan);
      if (duplicate) {
        midi1.sendNoteOn(note, velocities[t], chan + 1); 
      }
    }
    #ifdef DEBUG_VELOCITY
    Serial.print("meter_mean: "); Serial.print(meter_mean); Serial.print(" ");
    Serial.print(t_raw); Serial.print("->"); Serial.print(t); Serial.print(" * 128 us -> "); Serial.println(velocities[t]);
    #endif
    if (state != idle) {
      process(note_on, key, velocities[t]);
    }
}

void handleKeyUpEvent(byte key) {
    midi::DataByte note = key + A;
    byte chan;
    boolean layered = false;
    if (split_position == no_key) {
      chan = channel;
    } 
    else if (key < split_position) {
      // left section or whole keyboard
      chan = channel;
      note += left_transpose;
    } 
    else {
      // right section
      chan = channel + 1;
      note -= split_position >= 12 ? 12 : 0;
      layered = true;
    }
    chan &= 0xf;
    midi1.sendNoteOff(note, DefaultVelocity, chan);
    if (layered) {
      midi1.sendNoteOff(note, DefaultVelocity, chan + 1);
    }
    if (state != idle) {
      process(note_off, key, DefaultVelocity);
    }
}

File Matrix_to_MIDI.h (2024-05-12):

#pragma GCC optimize ("O3")

// max. value of a MIDI controller
const byte MIDI_CONTROLLER_MAX = 127;
const byte MIDI_CONTROLLER_MEAN = 64;


const int meter_pin = 2;
const int meter_led_pin = A3;
const byte meter_max = 255; // = 1*3*5*17 -> possible deltas
const byte meter_delta = 1;
const byte global_delta = 17;
//const byte meter_mean = (meter_max / (meter_delta*2)) * meter_delta;
// a cheap Conrad Elektronik meter of course is very non-linear, better measure the value
// when the pointer is in the middle
const byte meter_mean = 155;

/**
 * Considers that the meter is mounted upside down in the case.
 * @value to be displayed
 */
void display(int value) {
  analogWrite(meter_pin, meter_max - value);
}

/**
 * Channel 1 -> pointer is on the left.
 * Channel 10 -> pointer is on the right.
 */
void displayChannel(midi::Channel ch) {
  display((ch - 1) * meter_max / 9);
}

// how much differences from the mean sensitivity are
// magnified 
const int zoom = 3;
/**
 * Magnifies the difference from the display mean value.
 * @value raw value
 * @return zoomed value
 */
byte magnify(byte value) {
  // value = meter_mean is not changed by the transformation
  int magnified = zoom * (value - meter_mean) + meter_mean;
  if (magnified > meter_max) return meter_max;
  if (magnified < 0) return 0;
  return magnified;
}

/**
 * Roughly linearizes analog values as delivered
 * by an audio (logarithmic) potentiometer.
 * The pseudo linearization is implemented as
 * 2 sections of linear functions with different slopes.
 * @value non-linear input 0..1023
 * @return roughly linearized value 0..1023
 */
int delog(int value);

/*--------------------------------- persistent settings ---------------------------------*/

// the values in a fresh EEPROM
const byte invalid = 0xff;

/*--------- global settings ---------*/

float global_sens_to_exponent(byte sensitivity) {
  float ret = 1.0 - 0.5 * sensitivity / meter_max;
  Serial.print("exponent "); Serial.println(ret);
  return ret;
}

// start address of global settings storage area in EEPROM
const int SettingsAddress = 0;
const int n_keys = n_columns * n_rows;
typedef byte Sensitivities[n_keys]; 
Sensitivities sensitivities;

struct Settings {
  byte init;
  byte sensitivity;
  byte reserved2;
  byte reserved3;
  byte reserved4;
  byte reserved5;
  byte reserved6;
  byte reserved7;
  byte reserved8;
  byte reserved9;
  Sensitivities sensitivities;
};

Settings settings;

void printSettings() {
  Serial.print("global sensitivity "); Serial.println(settings.sensitivity);
  byte min_key_sens = 255; 
  byte max_key_sens = 0; 
  // find min. and max.
  for (int i = 0; i < n_keys; i++) {
    byte sens = settings.sensitivities[i];
    if (sens > max_key_sens)
      max_key_sens = sens;
    if (sens < min_key_sens)
      min_key_sens = sens;
  }
  // print
  for (int i = 0; i < n_keys; i++) {
    int sens = settings.sensitivities[i];
    Serial.print("sensitivity ");
    Serial.print(i);
    if (sens == max_key_sens) {
      Serial.print(" MAX ");
    } else if (sens == min_key_sens) {
      Serial.print(" min ");
    } else {
      Serial.print(" ");
    }
    Serial.println(sens);
  }
}

/**
 * Reads settings from EEPROM.
 * When the EEPROM still contains 0xff defaults,
 * reasonable initial values will be chosen for the settings.
 */
void readSettings() {
  // TODO checksum and detection of corrupt data
  byte *b = (byte*)&settings;
  for (int i = 0; i < sizeof(Settings); i++)
    b[i] = EEPROM.read(SettingsAddress + i);
  if (/*true ||*/ settings.init > 15) {
    // very first read 
    Serial.println("Starting with default settings!");
    Serial.print("All sensitivities will be "); Serial.println(meter_mean);
    settings.init = 0; 
    settings.sensitivity = meter_mean;
    for (int i = 0; i < n_keys; i++) {
      settings.sensitivities[i] = meter_mean;
    }
  }
  printSettings();
}

/**
 * Saves settings to EEPROM. To maximize EEPROM lifetime only changed values are actually written. 
 */
void saveSettings() {
  byte *b = (byte*)&settings;
  for (int i = 0; i < sizeof(Settings); i++) {
    byte original = EEPROM.read(SettingsAddress + i);
    if (original != b[i]) {
      EEPROM.write(SettingsAddress + i, b[i]);
      Serial.print("EEPROM ["); Serial.print(i); Serial.print("] <- "); Serial.println(b[i]);
    }
  }
}


/*--------------------------------- state event machine ---------------------------------*/

enum State { idle, global_sensitivity, key_sensitivity, wait_for_split, wait_for_preset};
enum Event { up_long, down_long, up_short, down_short, both, note_on, note_off, toggle_led };

void process(Event event, int value, int value2);

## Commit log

2017-04-10 Arduino pins wired to the 8*11 diode matrix
2017-04-22 started key velocity implementation, mapping values are not yet practical...
    [velocities.ods]
2017-04-24 better variant seems to be 1/sqrt(t) velocity
2017-04-24 velocity ~ 1/sqrt(t) seems to be better
2017-05-15 volt meter connected
2017-11-06 rocket switch increments/decrements analog meter now
2017-11-11 EEPROM und Statusmaschine implementiert, 1. Wurf
2017-12-27 bug fix in key velocity measurement
    [Matrix.h, Matrix_to_MIDI.ino]
2017-12-28 direct port i/o also for the rocker switch
2017-12-28 sensitivities are now considered in the calc. of MIDI velocities
2017-12-28 analog meter now also displays measured velocity, alternating with sensitivity
2018-04-30 ext. switch (sustain) and coding switch (MIDI channel) implemented not tested...
2019-05-26 switch from Microsoft to LibreOffice
2019-06-16 sustain pedal coupled to transpose settings in split mode transpose of left section can be toggled (0/+12) now, right is fix -12
    [Matrix_to_MIDI.ino]
2019-08-13 swapped split channels, now right channel is left channel plus 1
    [Matrix_to_MIDI.ino]
2019-11-17 Added a WARNING that current Arduino IDE 1.8.10 can not build this project!!!
2020-05-03 speed optimization -O3 and platform.txt, smaller data types make the Arduino faster
2020-05-09 velocity map now calculated with adjustable exponent (1 down to 0.5)
    Now everything feels perfect!!!
2020-05-17 fix wrong display of global dynamic setting, min. velocity now achieved
    [Dynamic.h, Matrix_to_MIDI.ino]
2022-02-13 ext control coding started, missing logarithm of ext. values
    [Matrix_to_MIDI.h, Matrix_to_MIDI.ino]
2022-02-24 logic tested and fixed, 1 wrong sound in AllCriedOut?
    [Matrix_to_MIDI.ino]
2022-03-24 revert wrong renaming expre->volume (accidentially mixed the volume knob with the external control/expression pedal)
    [Matrix_to_MIDI.ino]
2024-04-27 described new periphery, new circuit, new operation states
2024-05-12 simplified state event machine with the help of new event 'both' (both push buttons pressed)
2024-05-20 send external control value after change of registration, correct FM+MKS piano program change value
    [Matrix_to_MIDI.ino]
2024-08-29 Reset EQs and General MIDI on startup, added reverb and effect types to registrations.
    [Matrix_to_MIDI.ino]
2024-08-29 send GM Reset and flatten EQs also before sound/registration settings
    [Matrix_to_MIDI.ino]
2024-10-06 send min. value of 7 for MIDI velocity
2024-11-09 3D printer model for back and front plates
    [Matrix to MIDI Plates.stl]
2024-12-21 refurbished case + 3d printed panels
2025-12-30 fixed: screw holes are now really holes
    [Matrix to MIDI Plates.stl]
